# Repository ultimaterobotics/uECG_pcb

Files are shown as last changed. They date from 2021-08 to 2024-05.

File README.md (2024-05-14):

## uECG PCB version 4.52
 Changelog:

- Replaced AD8606 op amp with a pair of TLV271s;
- LDOs (3.3V for digital, 3V for analog side) were mixed in the previous version; strangely this didn’t affect functioning, but now this is fixed;
- Replaced BMI160 with LSM6DS3TR-C;
- Changed C6 capacitor from 2.2uF to 10uF for better low frequency performance;
- Replaced circuit protection (red LED) with diodes for more reliability;
- Changed charge resistor to 8.2K Ohm to fit the battery charging better;
- Replaced MCP71831 charger IC with TP4054; 
- Added thermistor for measuring temperature;
- Changed RGB LED to different part number;
- Added Ultimate Robotics logo on the back of the PCB.

## uECG device PCB version 4.5

PCB design in KiCAD. The main difference vs previous versions is that power is controlled via button, and slider switch is used only for long storage / shipping (and also to reset the firmware if something went really wrong).

Main project repository: https://github.com/ultimaterobotics/uECG

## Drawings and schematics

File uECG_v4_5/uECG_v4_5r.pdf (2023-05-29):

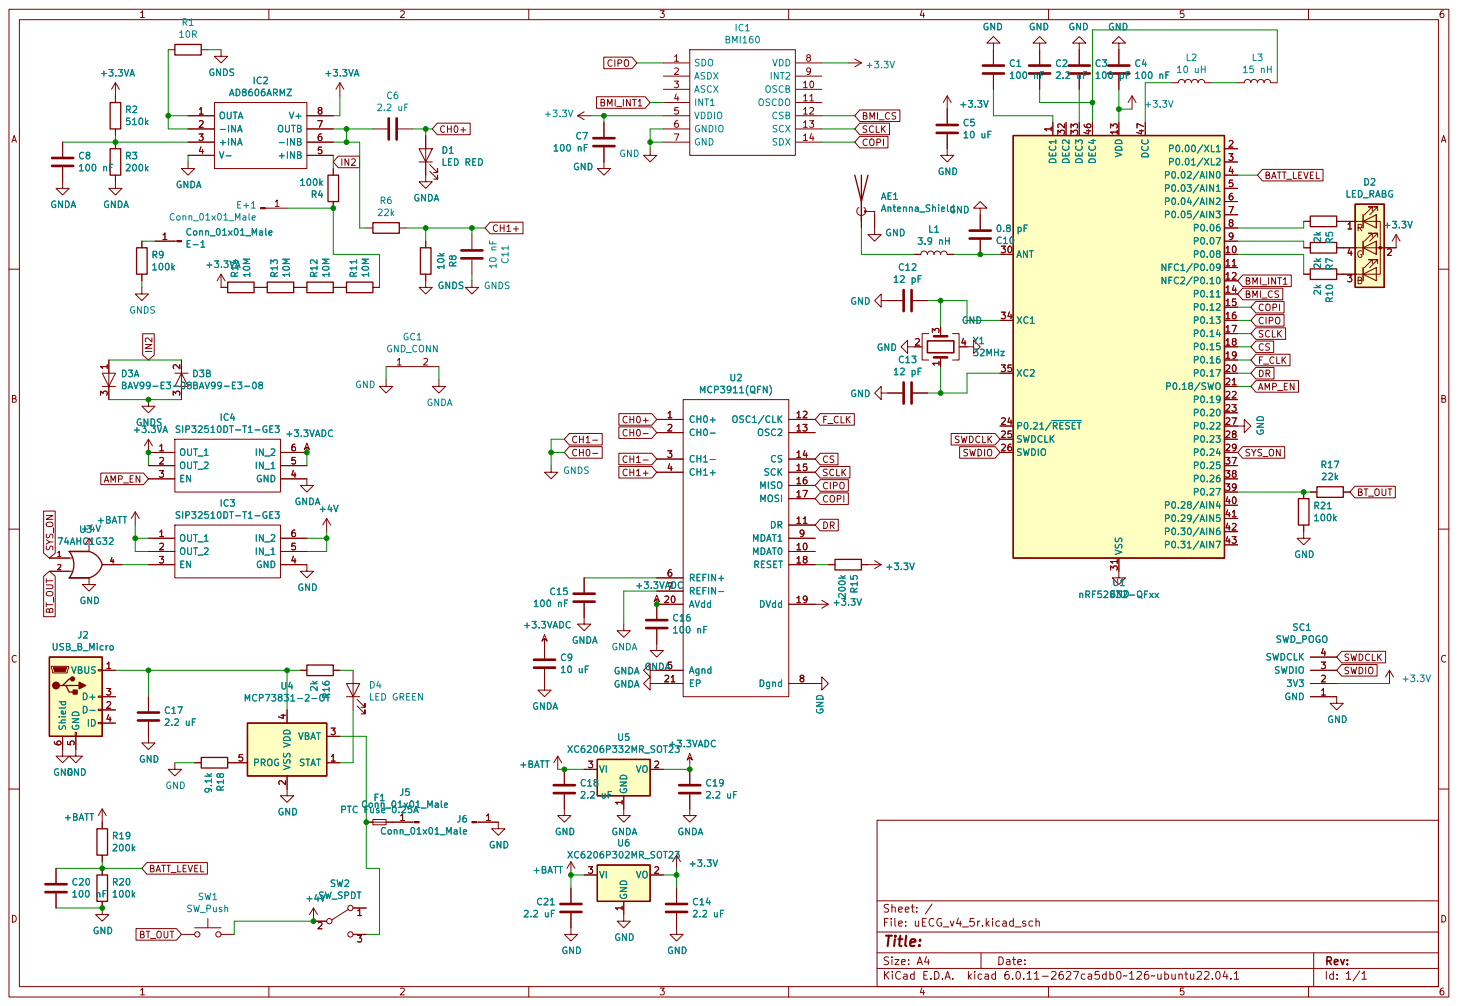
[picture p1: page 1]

100 nF GNDA GNDA GNDA C9

Id: 1/1 Title: File: uECG_v4_5r.kicad_sch Sheet: / C17

1 VO 2 VI 3 GND GND

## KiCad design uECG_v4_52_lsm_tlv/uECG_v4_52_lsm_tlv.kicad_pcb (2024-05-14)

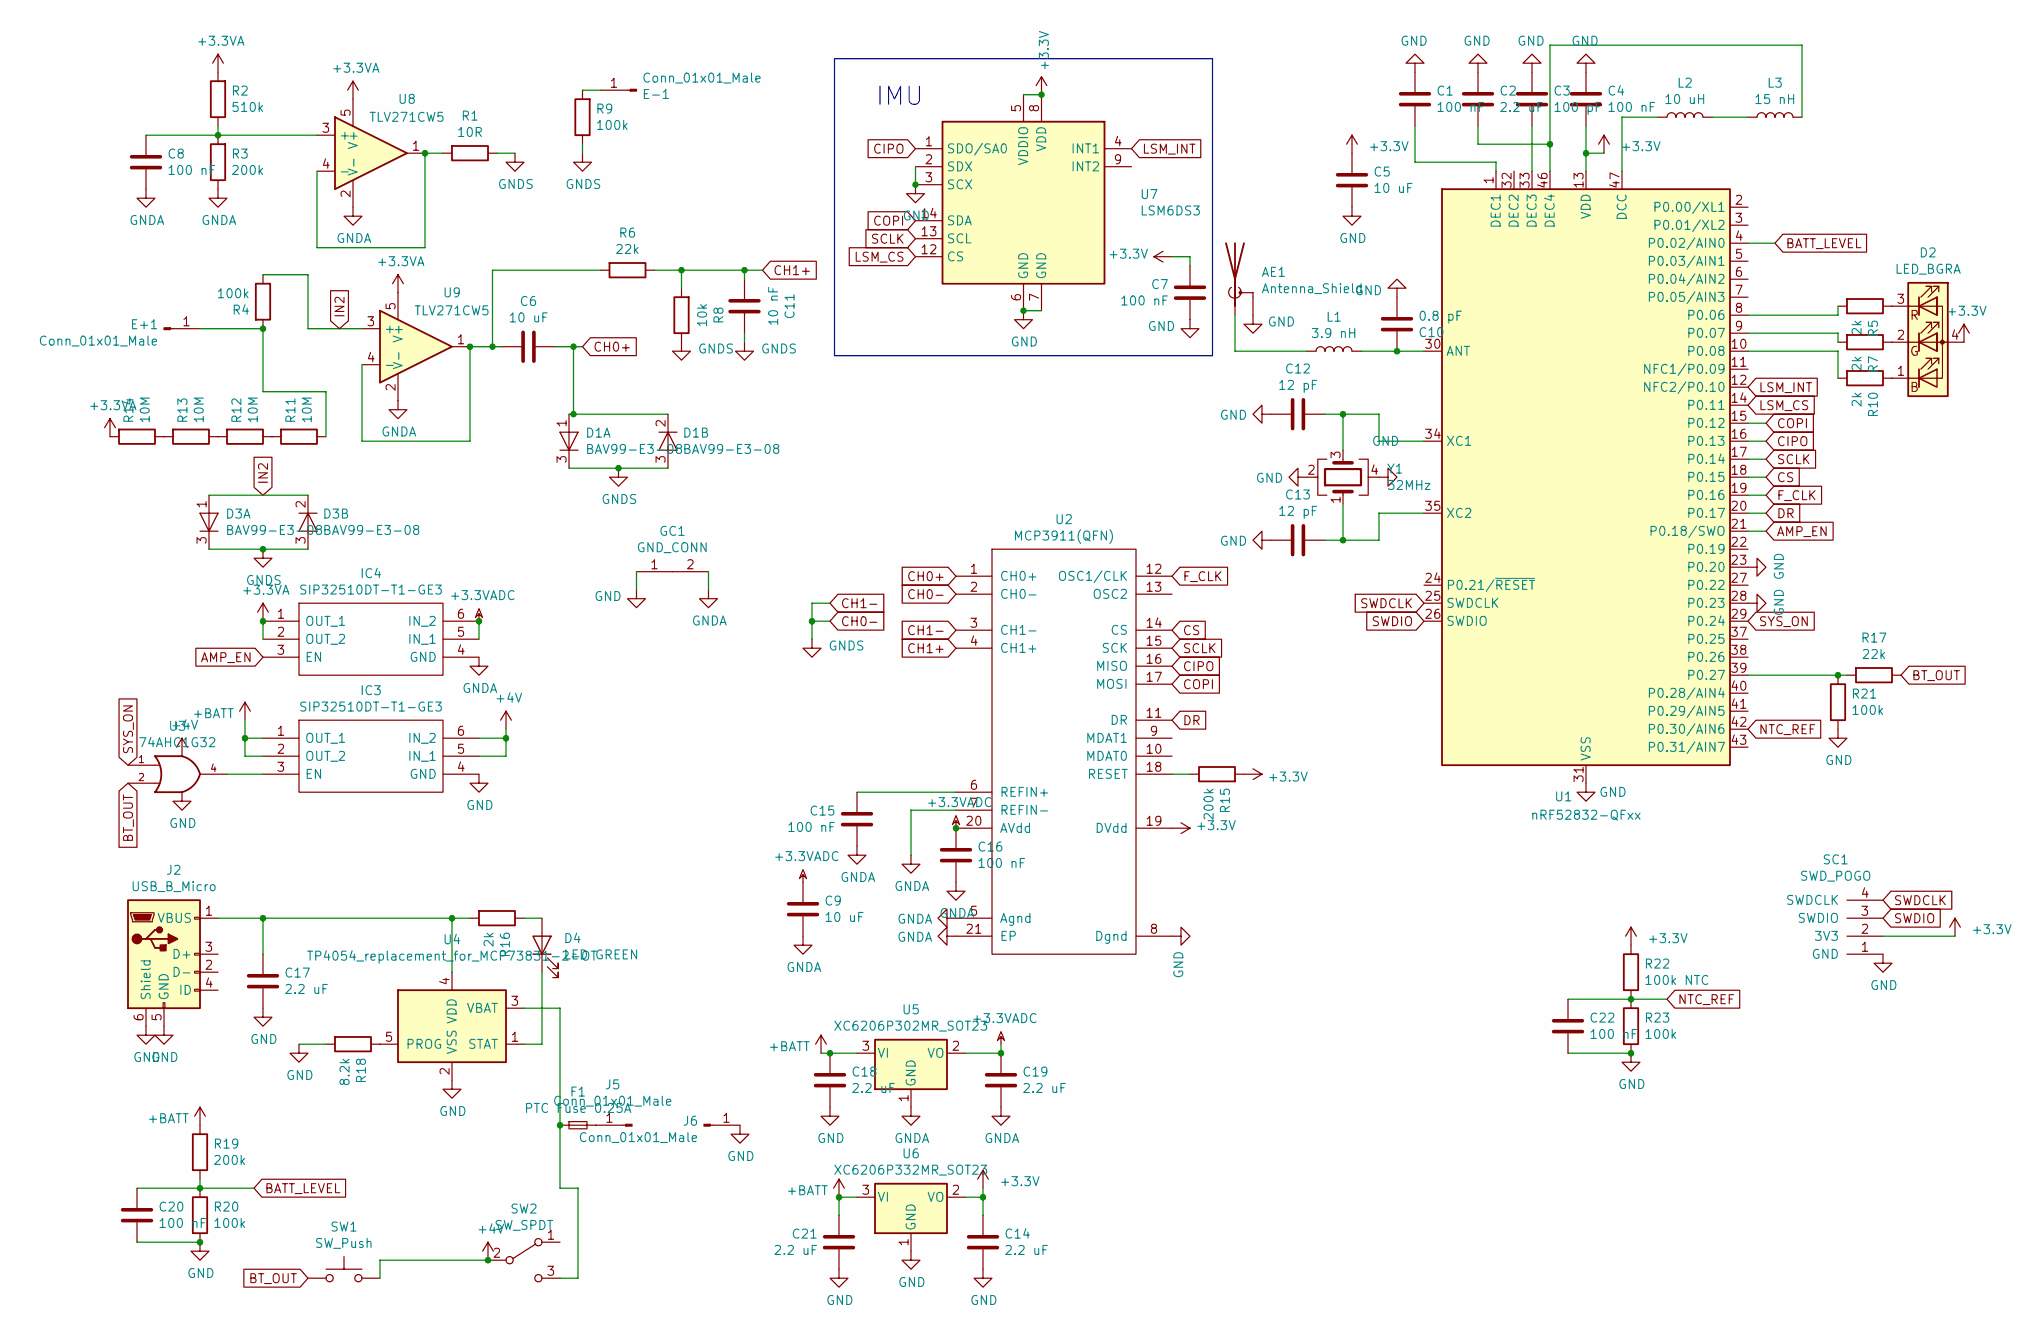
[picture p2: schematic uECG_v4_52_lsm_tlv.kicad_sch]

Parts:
AE1: Antenna_Shield; U.FL_Hirose_U.FL-R-SMT-1_Vertical; JLCPN C88373
C1, C4, C7, C8, C15, C16, C20, C22: 100 nF; C_0402_1005Metric; JLCPN C1525
C2, C14, C17, C18, C19, C21: 2.2 uF; C_0402_1005Metric; JLCPN C12530
C3: 100 pF; C_0402_1005Metric; JLCPN C106200
C5, C6, C9: 10 uF; C_0402_1005Metric; JLCPN C315248
C10: 0.8 pF; C_0402_1005Metric; JLCPN C88902
C11: 10 nF; C_0402_1005Metric; JLCPN C15195
C12, C13: 12 pF; C_0402_1005Metric; JLCPN C1547
D1, D3: BAV99-E3-08; SOT-23; JLCPN C2500
D2: LED_BGRA; LED_RGB_0603_a4; JLCPN C282128
D4: LED GREEN; LED_0603_1608Metric; JLCPN C72043
E+1: Conn_01x01_Male; PinHeader_1x01_P2.54mm_Vertical
E-1: Conn_01x01_Male; PinHeader_1x01_P2.54mm_Vertical
F1: PTC Fuse 0.25A; Fuse_0603_1608Metric; JLCPN C207011
GC1: GND_CONN
IC3, IC4: SIP32510DT-T1-GE3; TSOT-23-6; Manufacturer_Part_Number SIP32509DT-T1-GE3; JLCPN C145264
J2: USB_B_Micro; conn_usb_B_micro_smd_our
J5: Conn_01x01_Male; Pin_Header_Straight_1x01_Pitch2.54mm
J6: Conn_01x01_Male; PinHeader_1x01_P2.54mm_Vertical
L1: 3.9 nH; L_0402_1005Metric; JLCPN C14033
L2: 10 uH; L_0603_1608Metric; JLCPN C51942
L3: 15 nH; L_0402_1005Metric; JLCPN C27143
R1: 10R; R_0402_1005Metric; JLCPN C25077
R2: 510k; R_0402_1005Metric; JLCPN C11616
R3, R15, R19: 200k; R_0402_1005Metric; JLCPN C25764
R4, R9, R20, R21, R23: 100k; R_0402_1005Metric; JLCPN C25741
R5, R7, R10, R16: 2k; R_0402_1005Metric; JLCPN C4109
R6, R17: 22k; R_0402_1005Metric; JLCPN C25768
R8: 10k; R_0402_1005Metric; JLCPN C25744
R11, R12, R13, R14: 10М; R_0402_1005Metric; JLCPN C26082
R18: 8.2k; R_0402_1005Metric; JLCPN C25924
R22: 100k NTC; R_0402_1005Metric; JLCPN C77130
SC1: SWD_POGO
SW1: SW_Push; BTN_HY_1185
SW2: SW_SPDT; SW_SPDT_PCM12
U1: nRF52832-QFxx; QFN-48-1EP_6x6mm_Pitch0.4mm; JLCPN C77540
U2: MCP3911(QFN); QFN-20-1EP_4x4mm_P0.5mm_EP2.5x2.5mm
U3: 74AHC1G32; SOT-23-5; JLCPN C7470
U4: TP4054_replacement_for_MCP73831-2-OT; SOT-23-5; JLCPN C32574
U5: XC6206P302MR_SOT23; SOT-23; JLCPN C9972
U6: XC6206P332MR_SOT23; SOT-23; JLCPN C5446
U7: LSM6DS3; LGA-14_3x2.5mm_P0.5mm_LayoutBorder3x4y; JLCPN C967633
U8, U9: TLV271CW5; SOT-23-5; JLCPN C150498
Y1: 32MHz; Crystal_SMD_2016-4Pin_2.0x1.6mm; JLCPN C843260

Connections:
+3.3VA: IC4.1 (OUT_1), IC4.2 (OUT_2), R2.2, R14.2, U8.5 (V+), U9.5 (V+)
+3.3VADC: C9.2, C16.2, C19.2, IC4.5 (IN_1), IC4.6 (IN_2), U2.20 (AVdd), U5.2 (VO)
+3V3: C4.1, C5.2, C7.2, C14.2, D2.4 (A), R15.2, R22.1, SC1.2 (3V3), U1.13 (VDD), U1.36 (VDD), U1.48 (VDD), U2.19 (DVdd), U6.2 (VO), U7.5 (VDDIO), U7.8 (VDD)
+4V: IC3.5 (IN_1), IC3.6 (IN_2), SW1.2, SW2.2 (B), U3.5 (VCC)
+BATT: C18.2, C21.2, IC3.1 (OUT_1), IC3.2 (OUT_2), R19.1, U5.3 (VI), U6.3 (VI)
AMP_EN: IC4.3 (EN), U1.21 (P0.18/SWO)
BATT_LEVEL: C20.2, R19.2, R20.1, U1.4 (P0.02/AIN0)
BT_OUT: R17.1, SW1.1, U3.2
CH0+: C6.2, D1.1 (A), D1.2 (K), U2.1 (CH0+)
CH0-: C11.2, D1.3 (A), D3.3 (A), R1.1, R8.1, R9.1, U2.2 (CH0-), U2.3 (CH1-)
CH1+: C11.1, R6.1, R8.2, U2.4 (CH1+)
CIPO: U1.16 (P0.13), U2.16 (MISO), U7.1 (SDO/SA0)
COPI: U1.15 (P0.12), U2.17 (MOSI), U7.14 (SDA)
CS: U1.18 (P0.15), U2.14 (CS)
DR: U1.20 (P0.17), U2.11 (DR)
F_CLK: U1.19 (P0.16), U2.12 (OSC1/CLK)
GND: AE1.2 (Shield), C1.2, C2.2, C3.2, C4.2, C5.1, C7.1, C10.2, C12.1, C13.1, C14.1, C17.1, C18.1, C20.1, C21.1, C22.1, GC1.1, IC3.4 (GND), J2.5 (GND), J2.6 (Shield), J6.1, R18.2, R20.2, R21.2, R23.2, SC1.1 (GND), U1.23 (P0.20), U1.28 (P0.23), U1.31 (VSS), U1.45 (VSS), U1.49 (VSS), U2.8 (Dgnd), U3.3 (GND), U4.2 (VSS), U6.1 (GND), U7.2 (SDX), U7.3 (SCX), U7.6 (GND), U7.7 (GND), Y1.2, Y1.4
GNDA: C8.1, C9.1, C15.1, C16.1, C19.1, GC1.2, IC4.4 (GND), R3.1, U2.5 (Agnd), U2.7 (REFIN-), U2.21 (EP), U5.1 (GND), U8.2 (V-), U9.2 (V-)
IN2: D3.1 (A), D3.2 (K), R4.1, U9.3 (+)
LSM_CS: U1.14 (P0.11), U7.12 (CS)
LSM_INT: U1.12 (NFC2/P0.10), U7.4 (INT1)
NTC_REF: C22.2, R22.2, R23.1, U1.42 (P0.30/AIN6)
unnamed: AE1.1 (A), L1.1
unnamed: C1.1, U1.1 (DEC1)
unnamed: C2.1, L3.2, U1.46 (DEC4)
unnamed: C3.1, U1.33 (DEC3)
unnamed: C6.1, R6.2, U9.1, U9.4 (-)
unnamed: C8.2, R2.1, R3.2, U8.3 (+)
unnamed: C10.1, L1.2, U1.30 (ANT)
unnamed: C12.2, U1.34 (XC1), Y1.3
unnamed: C13.2, U1.35 (XC2), Y1.1
unnamed: C15.2, U2.6 (REFIN+)
unnamed: C17.2, J2.1 (VBUS), R16.2, U4.4 (VDD)
unnamed: D2.1 (BK), R10.1
unnamed: D2.2 (GK), R7.1
unnamed: D2.3 (RK), R5.1
unnamed: D4.1 (K), U4.1 (STAT)
unnamed: D4.2 (A), R16.1
unnamed: E+1.1, R4.2, R11.1
unnamed: E-1.1, R9.2
unnamed: F1.1, SW2.3 (C), U4.3 (VBAT)
unnamed: F1.2, J5.1
unnamed: IC3.3 (EN), U3.4
unnamed: L2.1, U1.47 (DCC)
unnamed: L2.2, L3.1
unnamed: R1.2, U8.1, U8.4 (-)
unnamed: R5.2, U1.8 (P0.06)
unnamed: R7.2, U1.9 (P0.07)
unnamed: R10.2, U1.10 (P0.08)
unnamed: R11.2, R12.1
unnamed: R12.2, R13.1
unnamed: R13.2, R14.1
unnamed: R15.1, U2.18 (RESET)
unnamed: R17.2, R21.1, U1.39 (P0.27)
unnamed: R18.1, U4.5 (PROG)
SCLK: U1.17 (P0.14), U2.15 (SCK), U7.13 (SCL)
SWDCLK: SC1.4 (SWDCLK), U1.25 (SWDCLK)
SWDIO: SC1.3 (SWDIO), U1.26 (SWDIO)
SYS_ON: U1.29 (P0.24), U3.1

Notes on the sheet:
IMU

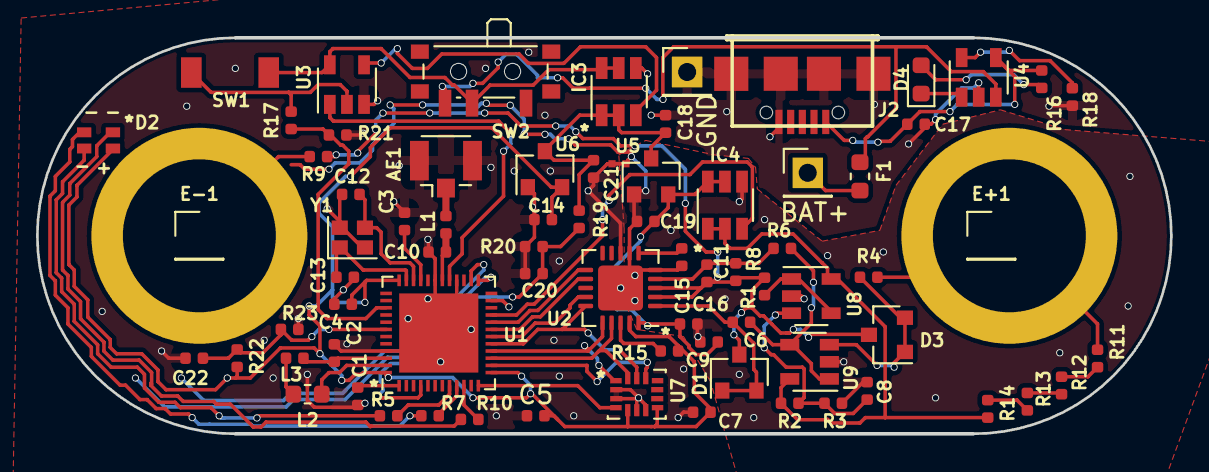
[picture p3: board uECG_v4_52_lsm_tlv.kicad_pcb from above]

Board: 2 copper layers, 63.0 x 22.0 mm, 75 parts (1 on the bottom side), 59 nets.

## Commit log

2021-08-31 PCB design in KiCAD
    [uECG_v4_5.kicad_pcb, uECG_v4_5.sch]
2023-05-29 added schematics PDF
2024-05-14 Added latest uECG version (v4_52)
    Uploaded KiCAD PCB files for v4_52
    [uECG_v4_52_lsm_tlv.kicad_pcb, uECG_v4_52_lsm_tlv.kicad_sch, uECG_v4_52_lsm_tlv.sch]
